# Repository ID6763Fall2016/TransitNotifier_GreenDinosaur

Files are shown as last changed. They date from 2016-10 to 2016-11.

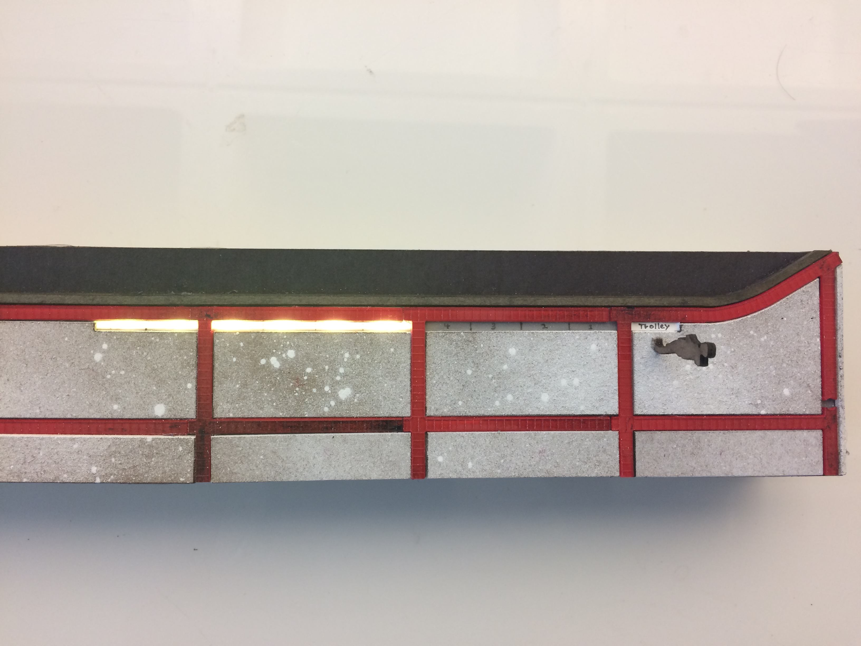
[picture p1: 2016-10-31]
Photos/2016-10-25 11.32.36.jpg

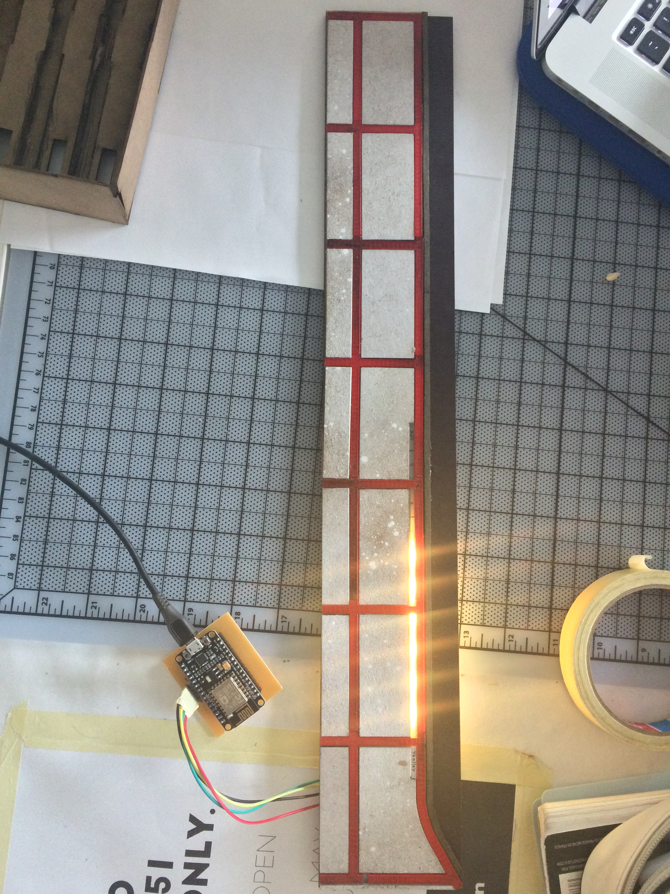
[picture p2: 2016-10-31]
Photos/2016-10-24 17.50.49 HDR.jpg

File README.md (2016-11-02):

# Transit Notifier - Green Dinosaur

This is the repository for the "Transit Tiles" Transit Notifier by Hareen Godthi and John Kimionis.
Read our blog post and wiki pages for description and setup instructions.

##Bill of Materials
Model Fabrication
* 1/16” chipboard (http://www.dickblick.com/products/crescent-chipboard-packs/)
* 1/16” clear acrylic (http://www.dickblick.com/products/acrylic-clear-sheets/)
* Spray paint in black, gray, red, and white (http://www.dickblick.com/search/?q=spray%20paint&x=0&y=0&sp_cs=UTF-8)
* Vellum (http://www.dickblick.com/products/canson-vidalon-vellum/)
* Spray adhesive (http://www.dickblick.com/products/elmers-spray-adhesive/)

Circuit
* 1 ESP8266-12E board (Amica NodeMCU) (https://www.amazon.com/HiLetgo-Version-NodeMCU-Internet-Development/dp/B010O1G1ES/)
* 1 USB-to-microUSB cable (https://www.amazon.com/AmazonBasics-Micro-USB-USB-2-0-Cable/dp/B00NH124VM/)
* 1 5V USB power bank (https://www.amazon.com/RAVPower-Smallest-Powerful-Portable-External/dp/B00ZZYBAI2/)
* 1 SMD 603 feed-through capacitor (http://www.digikey.com/product-detail/en/johanson-dielectrics-inc/100X14X105MV4T/709-1334-1-ND/2327234)
* 1 piece of FR1 board (https://www.amazon.com/sheets-Bakelite-phenol-laminate-microns/dp/B00IMG44PG/)

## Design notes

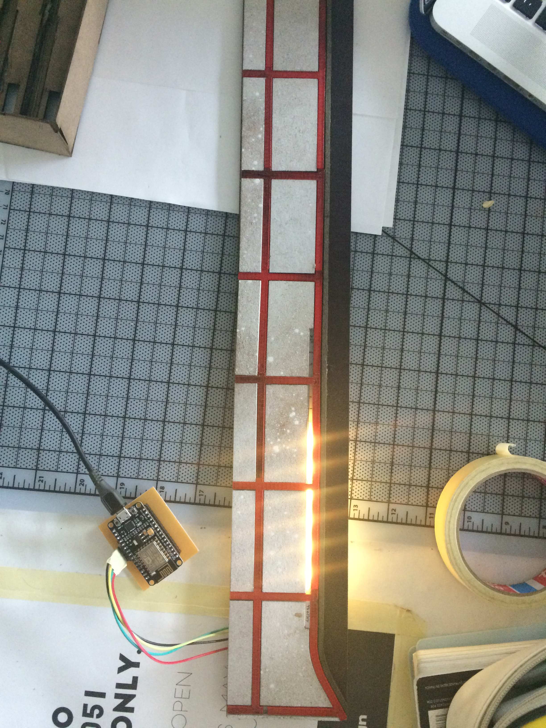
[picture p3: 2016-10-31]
Photos/2016-10-24 17.50.37.jpg

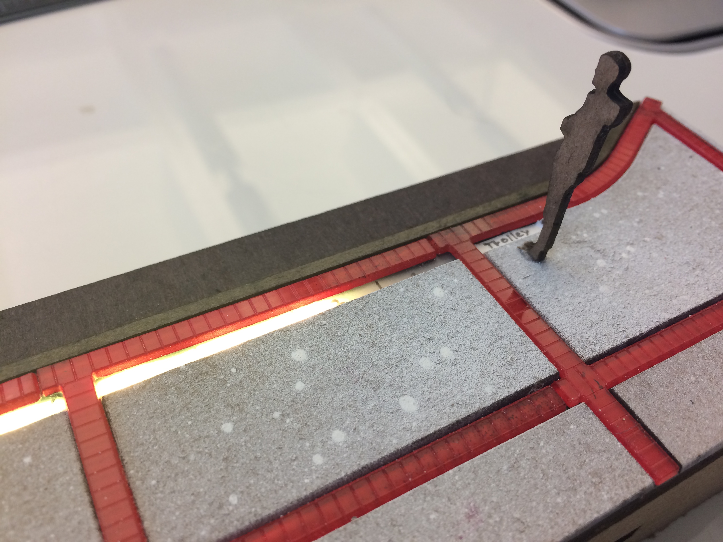
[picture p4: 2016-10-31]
Photos/2016-10-25 11.32.22.jpg

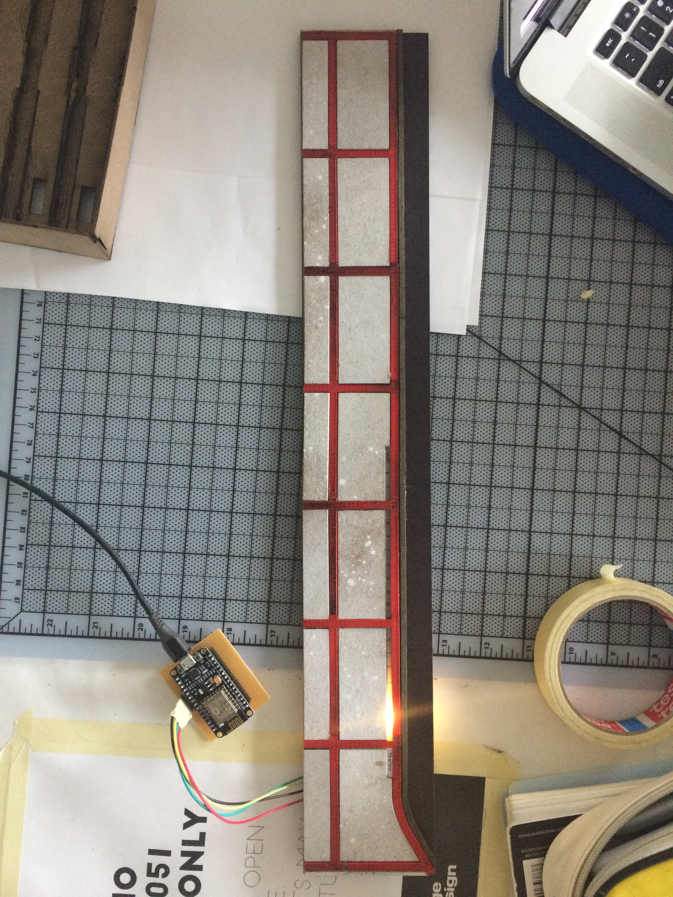
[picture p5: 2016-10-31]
Photos/2016-10-24 17.49.03.jpg

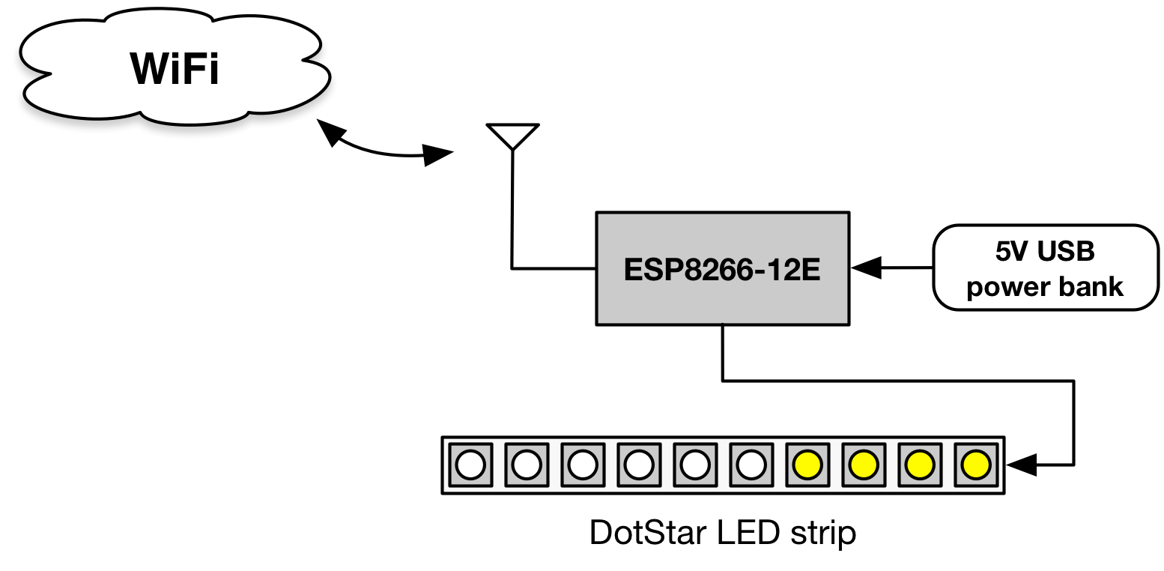
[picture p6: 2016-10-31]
Photos/block_diagram.png

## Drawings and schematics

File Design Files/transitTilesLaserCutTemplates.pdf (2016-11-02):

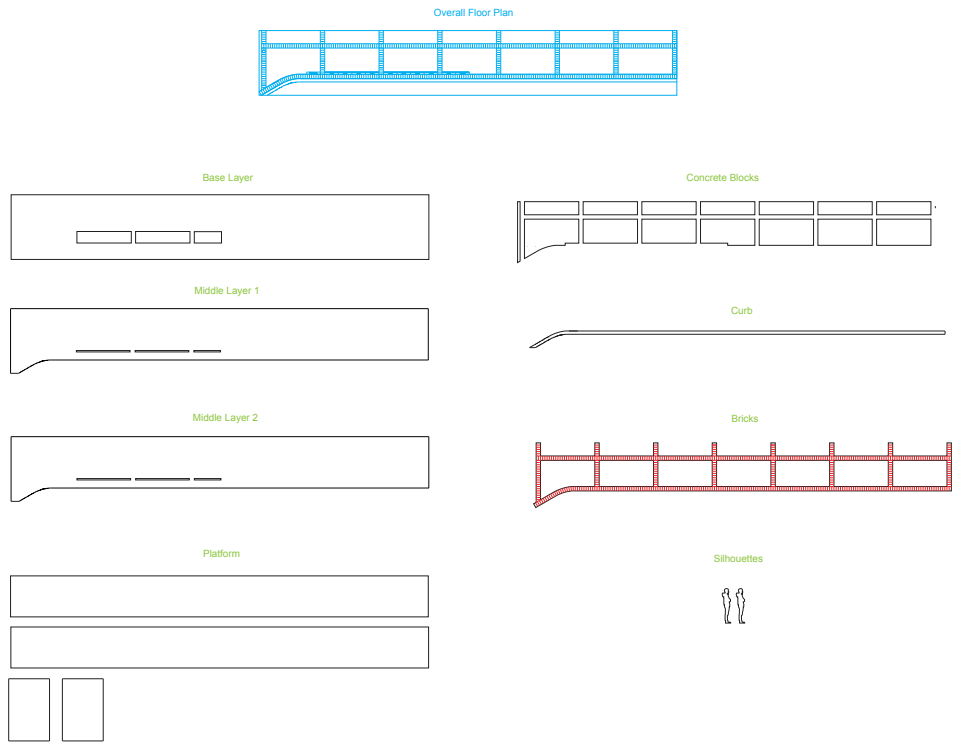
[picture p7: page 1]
Base Layer; Middle Layer 1; Middle Layer 2; Concrete Blocks; Curb; Bricks; Platform; Silhouettes

Overall Floor Plan

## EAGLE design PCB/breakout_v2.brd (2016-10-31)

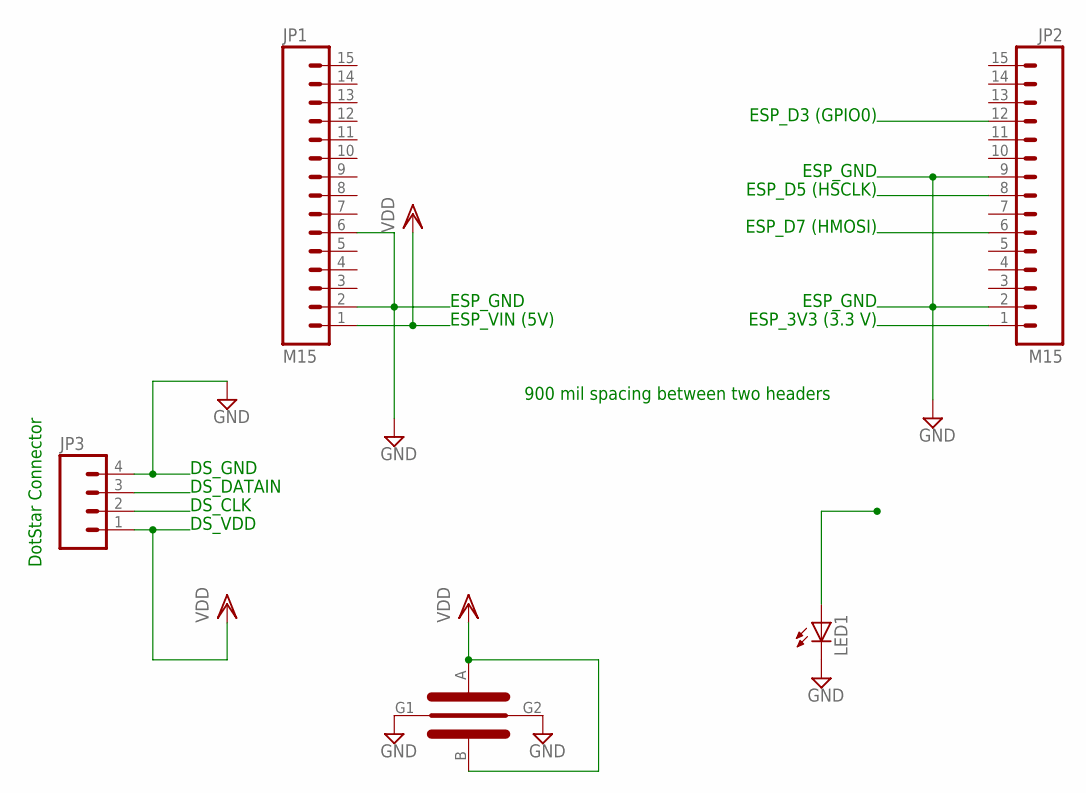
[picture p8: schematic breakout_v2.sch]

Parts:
JP1, JP2: M15; 1X15
JP3: M04PTH; 1X04
LED1: LED5MM
U$1: X2Y_CAP; 0603(X14)

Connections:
DS_CLK: JP2.8, JP3.2
DS_DATAIN: JP2.6, JP3.3
GND: JP1.2, JP1.6, JP2.2, JP2.9, JP3.4, LED1.K (C), U$1.G1, U$1.G2
LED_PIN: JP2.12, LED1.A
VDD: JP1.1, JP3.1, U$1.A, U$1.B

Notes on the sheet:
DotStar Connector
DS_GND
DS_DATAIN
DS_CLK
DS_VDD
ESP_GND
ESP_VIN (5V)
ESP_3V3 (3.3 V)
ESP_D7 (HMOSI)
ESP_D5 (HSCLK)
ESP_D3 (GPIO0)
900 mil spacing between two headers

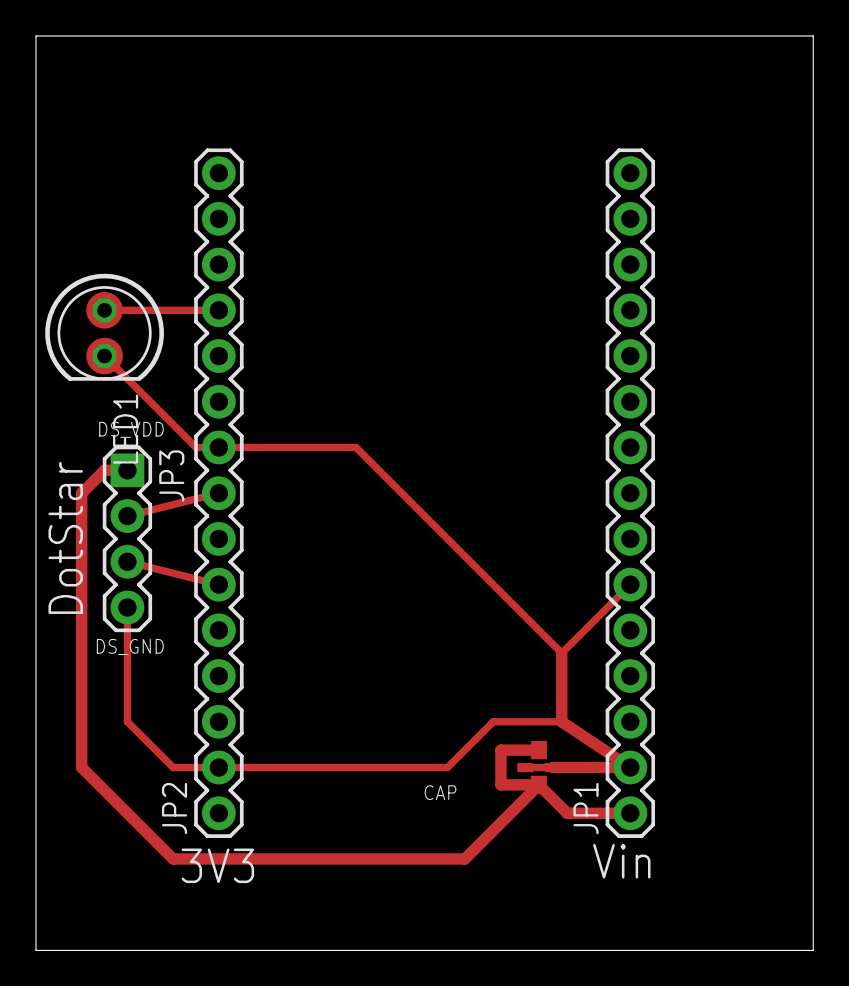
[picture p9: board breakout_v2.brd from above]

Board: 2 copper layers, 43.2 x 50.8 mm, 5 parts (0 on the bottom side), 5 nets.

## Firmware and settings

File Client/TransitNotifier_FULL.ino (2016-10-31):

#define ENABLE_DEBUG           1
#define ENABLE_ESP8266_DEBUG   0

#include <Adafruit_DotStar.h>
// Because conditional #includes don't work w/Arduino sketches...
#include <SPI.h>         // COMMENT OUT THIS LINE FOR GEMMA OR TRINKET
//#include <avr/power.h> // ENABLE THIS LINE FOR GEMMA OR TRINKET

#define NUMPIXELS 13 // Number of LEDs in strip

// Here's how to control the LEDs from any two pins:
//#define DATAPIN    14
//#define CLOCKPIN   12
#define DATAPIN    13
#define CLOCKPIN   14
Adafruit_DotStar strip = Adafruit_DotStar(
                           NUMPIXELS, DATAPIN, CLOCKPIN, DOTSTAR_BRG);
// The last parameter is optional -- this is the color data order of the
// DotStar strip, which has changed over time in different production runs.
// Your code just uses R,G,B colors, the library then reassigns as needed.
// Default is DOTSTAR_BRG, so change this if you have an earlier strip.

// Hardware SPI is a little faster, but must be wired to specific pins
// (Arduino Uno = pin 11 for data, 13 for clock, other boards are different).
//Adafruit_DotStar strip = Adafruit_DotStar(NUMPIXELS, DOTSTAR_BRG);

#define LED   0

#define YELLOW_COLOR  0xFFFF00
//#define YELLOW_COLOR  0xAAAA00  // lower intensity yellow

#include <Arduino.h>
#include <ArduinoJson.h>

#include <ESP8266WiFi.h>
#include <ESP8266WiFiMulti.h>

#include <ESP8266HTTPClient.h>

#define SERVER_ADDRESS  "X.X.X.X:3000"    // Node.js server IP:Port
#define WIFI_SSID       "WiFi_name"
#define WIFI_KEY        "WiFi_pass"

ESP8266WiFiMulti WiFiMulti;

void setup() {

///////// DotStar
  pinMode(LED, OUTPUT);

#if defined(__AVR_ATtiny85__) && (F_CPU == 16000000L)
  clock_prescale_set(clock_div_1); // Enable 16 MHz on Trinket
#endif

  strip.begin(); // Initialize pins for output
  strip.show();  // Turn all LEDs off ASAP


///////// ESP8266

  Serial.begin(115200);

#if ENABLE_ESP8266_DEBUG
  // enable diagnostic output from WiFi libraries
  // and enable output from printf()
  Serial.setDebugOutput(true);
#endif

  Serial.println();
  Serial.println();
  Serial.println();

  for (uint8_t t = 4; t > 0; t--) {
    Serial.printf("[SETUP] WAIT %d...\n", t);
    Serial.flush();
    delay(1000);
  }

  /* Connect to SSID with WPA */
  WiFiMulti.addAP(WIFI_SSID, WIFI_KEY);

  /* Show ESP8266 Client MAC address */
  String clientMac = "";

  unsigned char mac[6];
  WiFi.macAddress(mac);
  clientMac += macToStr(mac);

  Serial.println("Client MAC: " + clientMac);

}

void loop() {

  // wait for WiFi connection
  if ((WiFiMulti.run() == WL_CONNECTED)) {

#if ENABLE_DEBUG
    Serial.println("");
    Serial.println("WiFi connected");
    Serial.println("IP address: ");
    Serial.println(WiFi.localIP());
#endif

    String payload = getHTTP("http://" + SERVER_ADDRESS + "/trolley_to_HUB_stop_Klaus", "");
    Serial.print(payload + " minutes.");

    int minutes = payload.toInt();
    setPixelTimeline(minutes, YELLOW_COLOR);

  }
  else {
    Serial.printf("No WiFi");
  }

//  delay(5000);
  delay(500);
}


/* convert MAC address to string */
String macToStr(const uint8_t* mac)
{
  String result;
  for (int i = 0; i < 6; ++i) {
    result += String(mac[i], 16);
    if (i < 5)
      result += ':';
  }
  return result;
}



/* GET the payload of an HTTP response */
String getHTTP(String url, String SHA_fingerprint) {

  String payload = "ERROR";

  HTTPClient http;

#if ENABLE_DEBUG
  Serial.print("[HTTP] begin...\n");
#endif

  if (SHA_fingerprint.length() > 0) {
    http.begin(url, SHA_fingerprint); //HTTPS
  }
  else {
    http.begin(url); //HTTP
  }


#if ENABLE_DEBUG
  Serial.print("[HTTP] GET...\n");
#endif

  // start connection and send HTTP header
  int httpCode = http.GET();

  // httpCode will be negative on error
  if (httpCode > 0) {
    // HTTP header has been send and Server response header has been handled
#if ENABLE_DEBUG
    Serial.printf("[HTTP] GET... code: %d\n", httpCode);
#endif

    // file found at server
    if (httpCode == HTTP_CODE_OK) {
      payload = http.getString();
#if ENABLE_DEBUG
      Serial.println(payload);
#endif
    }
  }
  else {
    Serial.printf("[HTTP] GET... failed, error: %s\n", http.errorToString(httpCode).c_str());
  }

  http.end();

  return payload;

}


void setPixelTimeline(int minutes, int color) {

  // first LED always on, it represents the "> 10 minutes, so you'd better walk" case
  strip.setPixelColor(0, color);

  if (minutes < 10) {
    for (int i = 1; i < 10 - minutes; ++i) {
      strip.setPixelColor(i, color); // 'On' pixels
    }
    for (int i = 10 - minutes; i <= 10; ++i) {
      strip.setPixelColor(i, 0x000000); // 'Off' all remaining pixels
    }

  }
  else {
    for (int i = 1; i <= 10; ++i) {
      strip.setPixelColor(i, 0x000000); // 'Off' all remaining pixels
    }
  }

  strip.show();
}

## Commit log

2016-10-31 design files
    [breakout_v2.brd, breakout_v2.sch]
2016-11-02 update BOM

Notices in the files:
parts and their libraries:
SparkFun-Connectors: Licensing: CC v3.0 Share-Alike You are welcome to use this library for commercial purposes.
